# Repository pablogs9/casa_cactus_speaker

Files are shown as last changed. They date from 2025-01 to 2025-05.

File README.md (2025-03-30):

# Casa Cactus Speaker

3d
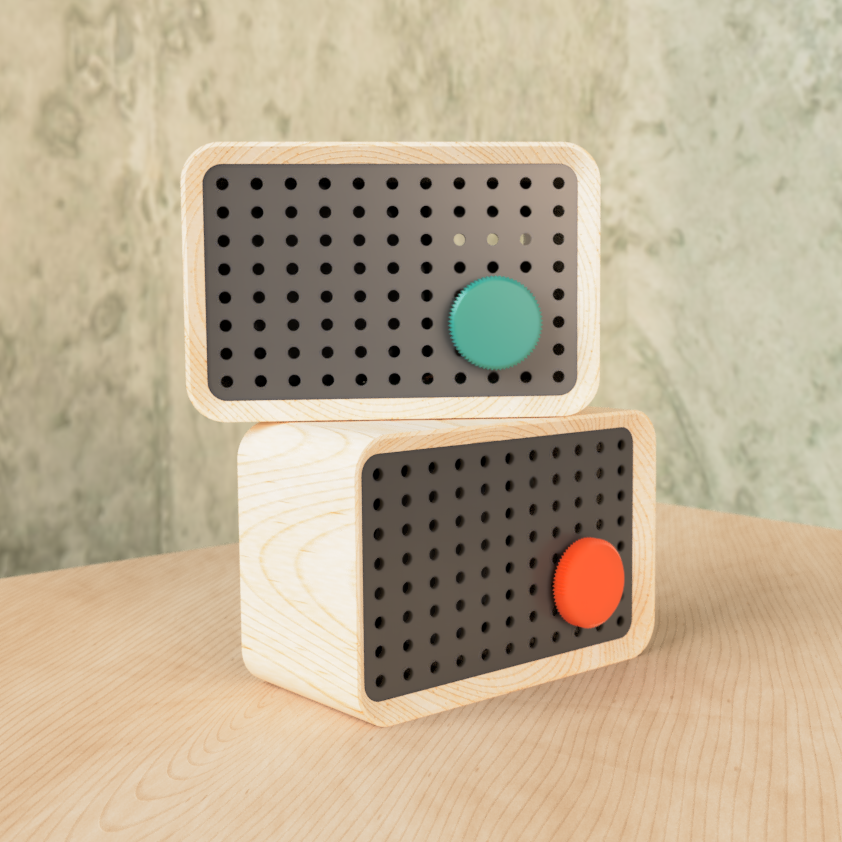
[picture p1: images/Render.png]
Render


Repository for a project featuring an ESP32-S3 and an I2S Class D amplifier for audio playback.

Created for a Makespace Madrid session to demonstrate a complete PCB design workflow, from schematic to JLCPCB fabrication.

**Companion slides: [here](https://docs.google.com/presentation/d/1glYFRo9XCKRI-qDjp1DA8M3mJohLk-lrxx0JoBPsboM/edit#slide=id.p)**

PCB
Schematic

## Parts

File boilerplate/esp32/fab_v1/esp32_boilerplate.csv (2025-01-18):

Designator | Value | LCSC part number
C1 | 0.1u | C14663
C2,C3 | 22u (Tantalum) | C129272
LED1,LED2 | KT-0603R | C2286
R1,R2 | 5k1 | C23186
R3,R7 | 100 | C22775
SW1,SW2 | TS-1187A-B-A-B | C318884
U1 | CH340C_C7464026 | C7464026
U2 | AMS1117-3.3 | C6186
U3 | ESP32-WROOM-32E(8MB) | C701342
USBC1 | TYPE-C-31-M-12 | C165948

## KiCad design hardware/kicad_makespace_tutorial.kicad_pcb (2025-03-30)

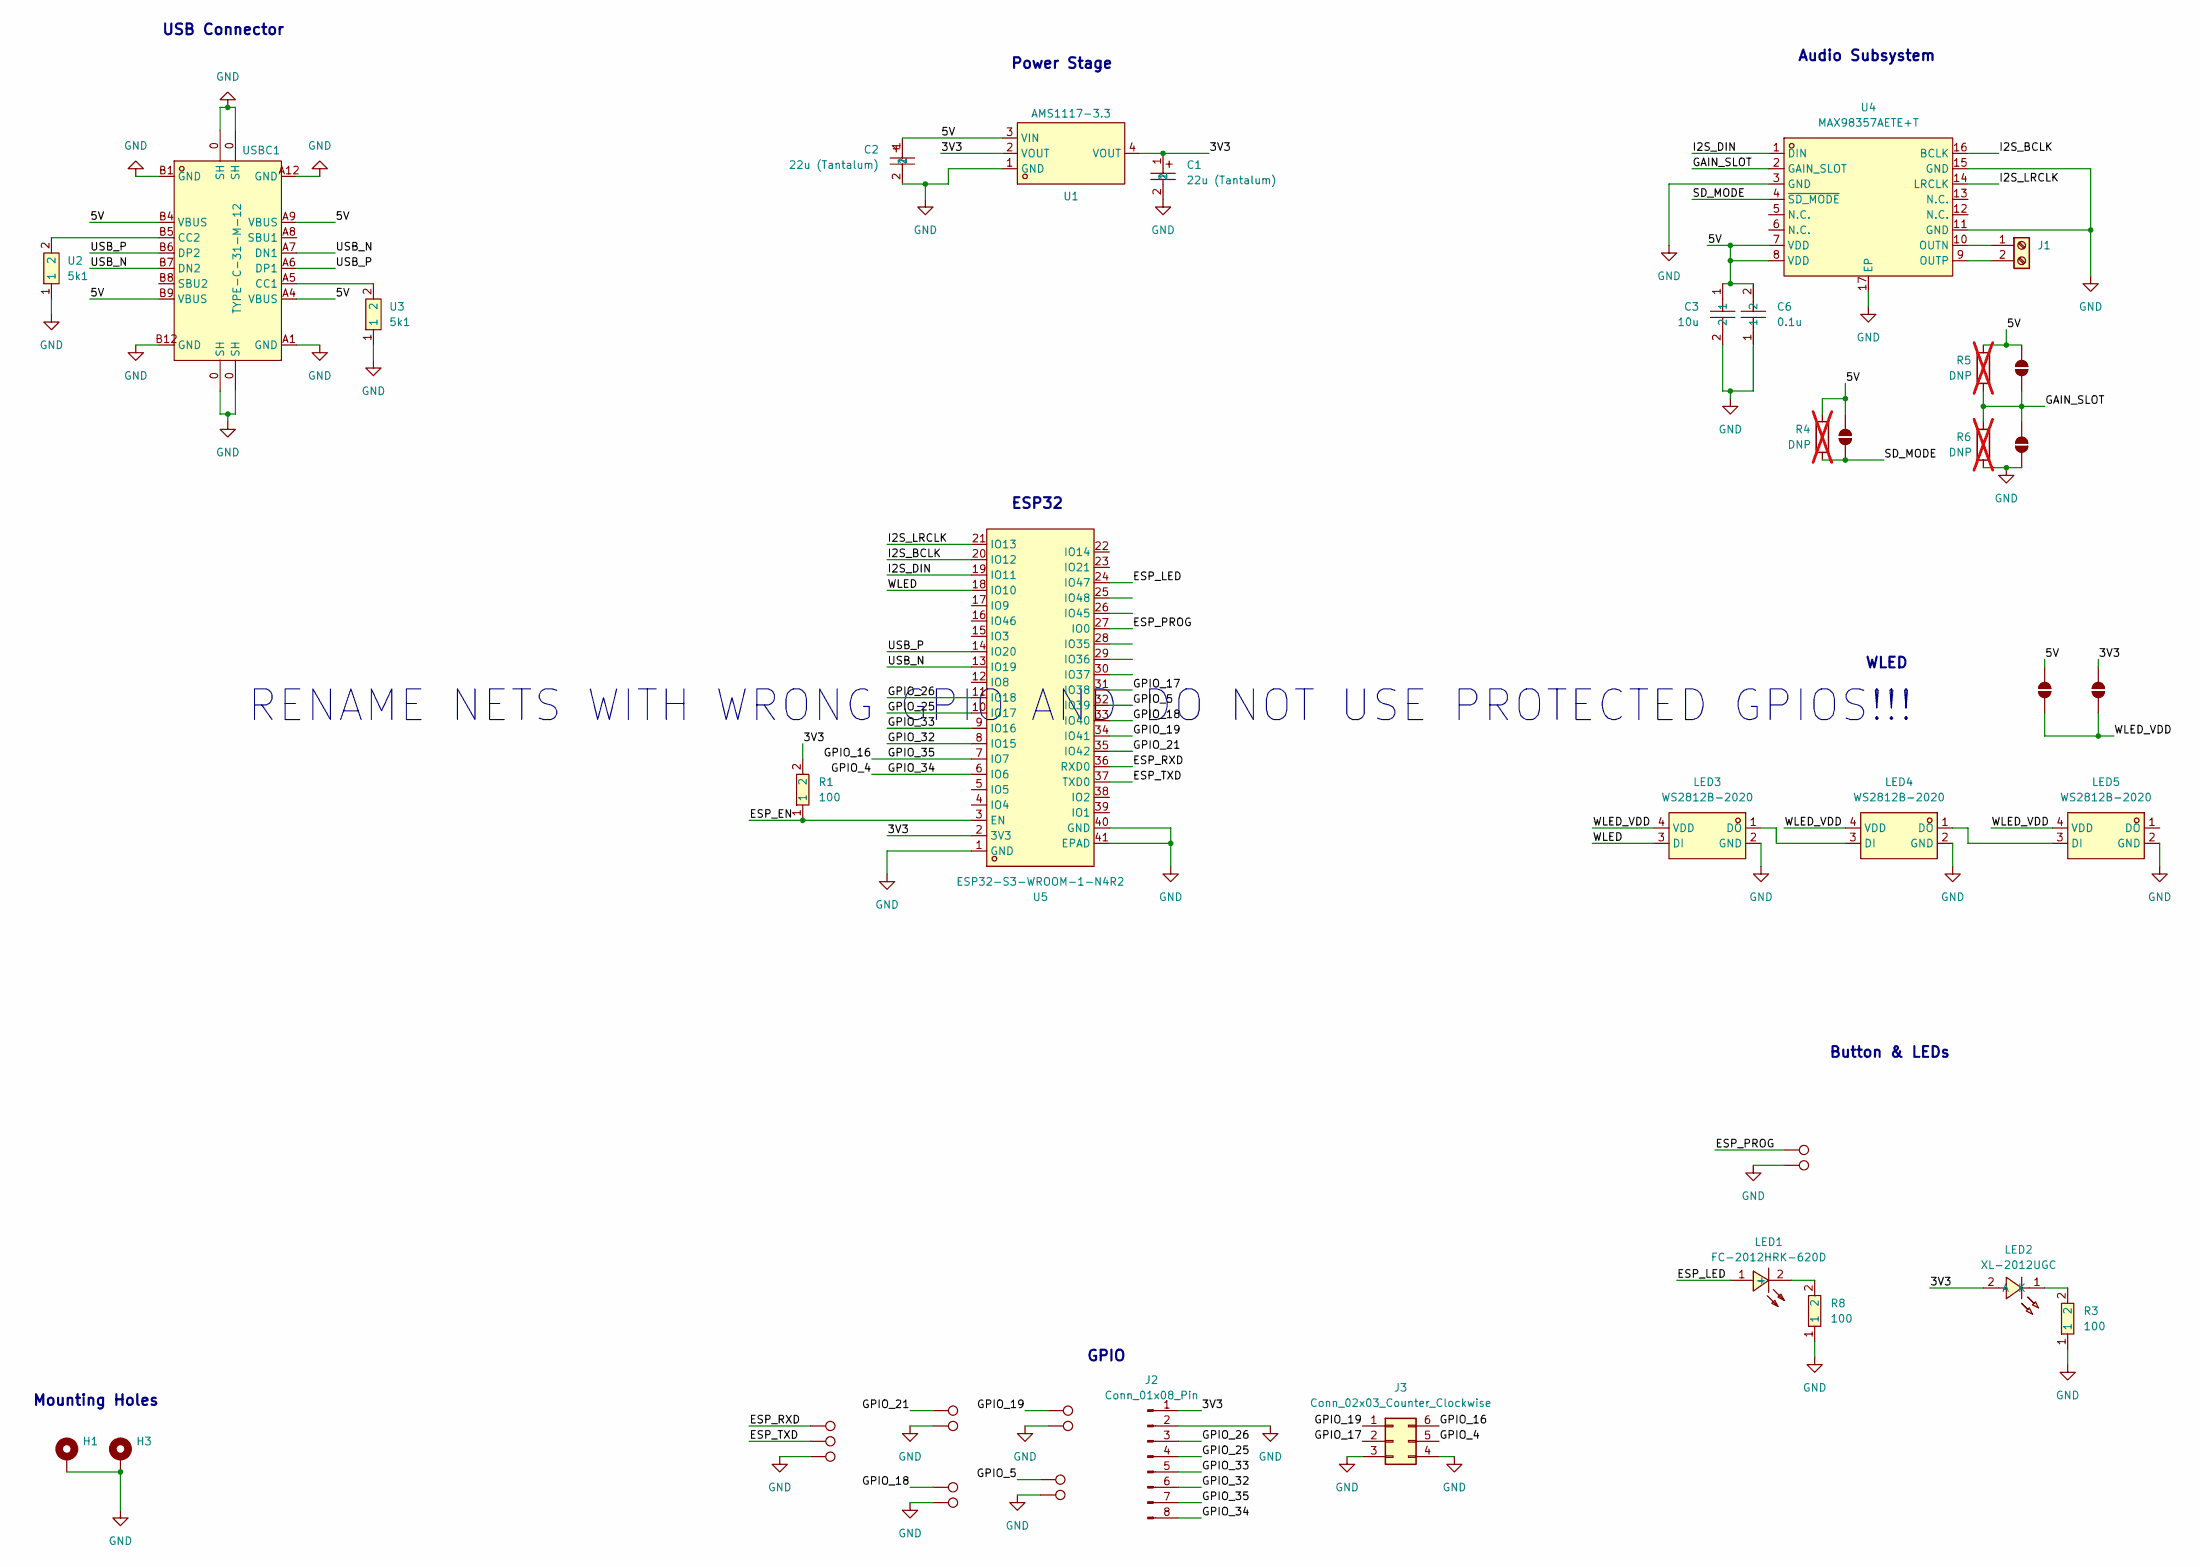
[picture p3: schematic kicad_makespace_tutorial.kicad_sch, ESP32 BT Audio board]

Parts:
C1, C2: 22u (Tantalum); CASE-A_3216; LCSC Part C129272
C3: 10u; C0805; LCSC Part C15850
C6: 0.1u; C0805; LCSC Part C49678
H1, H3: MountingHole_Pad_MP; MountingHole_2.7mm_M2.5_DIN965_Pad
J1: Screw_Terminal_01x02; CONN-TH_2P-P5.00_WJ128V-5.0-2P
J2: Conn_01x08_Pin; PinHeader_1x08_P1.27mm_Vertical_SMD_Pin1Right
J3: Conn_02x03_Counter_Clockwise; PinHeader_2x03_P2.54mm_Vertical
JP1, JP2, JP3, JP4, JP5: SolderJumper_2_Open; SolderJumper-2_P1.3mm_Open_TrianglePad1.0x1.5mm
LED1: FC-2012HRK-620D; LED0805-R-RD; LCSC Part C84256
LED2: XL-2012UGC; LED0805-RD_GREEN; LCSC Part C965815
LED3, LED4, LED5: WS2812B-2020; LED-SMD_4P-L2.0-W2.0-TL_WS2812B-2020; LCSC Part C965555
R1, R3, R8: 100; R0805; LCSC Part C17408
R4, R5, R6: DNP; R_0805_2012Metric_Pad1.20x1.40mm_HandSolder; not fitted
TP1, TP2, TP3, TP4, TP5, TP6, TP12, TP13, TP15, TP16, TP17, TP18, TP19: TestPoint; TestPoint_Pad_D1.0mm
U1: AMS1117-3.3; SOT-223-3_L6.5-W3.4-P2.30-LS7.0-BR; LCSC Part C6186
U2, U3: 5k1; R0805; LCSC Part C2930296
U4: MAX98357AETE+T; TQFN-16_L3.0-W3.0-P0.50-BL-EP1.5; LCSC Part C910544
U5: ESP32-S3-WROOM-1-N4R2; WIRELM-SMD_ESP32-S3-WROOM-1; LCSC Part C2913203
USBC1: TYPE-C-31-M-12; USB-C_SMD-TYPE-C-31-M-12; LCSC Part C165948

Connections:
/3V3: C1.1, J2.1, JP5.2 (B), LED2.2 (A), R1.2, U1.2 (VOUT), U1.4 (VOUT), U5.2 (3V3); also elsewhere on the board
/5V: C2.1, C3.1, C6.2, JP1.2 (B), JP3.2 (B), JP4.2 (B), R4.1, R5.1, U1.3 (VIN), U4.7 (VDD), U4.8 (VDD), USBC1.A4 (VBUS), USBC1.A9 (VBUS), USBC1.B4 (VBUS), USBC1.B9 (VBUS); also elsewhere on the board
/ESP_EN: R1.1, U5.3 (EN)
/ESP_LED: LED1.1 (+), U5.24 (IO47)
/ESP_PROG: TP18.1, U5.27 (IO0)
/ESP_RXD: TP15.1, U5.36 (RXD0)
/ESP_TXD: TP16.1, U5.37 (TXD0)
/GAIN_SLOT: JP2.2 (B), JP3.1 (A), R5.2, R6.1, U4.2 (GAIN_SLOT)
/GPIO_5: TP12.1, U5.32 (IO39)
/GPIO_16: J2.7, J3.6, U5.7 (IO7)
/GPIO_17: J3.2, U5.31 (IO38)
/GPIO_18: TP5.1, U5.33 (IO40)
/GPIO_19: J3.1, TP3.1, U5.34 (IO41)
/GPIO_21: TP2.1, U5.35 (IO42)
/GPIO_25: J2.4, U5.10 (IO17)
/GPIO_26: J2.3, U5.11 (IO18)
/GPIO_32: J2.6, U5.8 (IO15)
/GPIO_33: J2.5, U5.9 (IO16)
/GPIO_34: J2.8, J3.5, U5.6 (IO6)
/I2S_BCLK: U4.16 (BCLK), U5.20 (IO12)
/I2S_DIN: U4.1 (DIN), U5.19 (IO11)
/I2S_LRCLK: U4.14 (LRCLK), U5.21 (IO13)
/SD_MODE: JP1.1 (A), R4.2, U4.4 (~SD_MODE)
/USB_N: U5.13 (IO19), USBC1.A7 (DN1), USBC1.B7 (DN2)
/USB_P: U5.14 (IO20), USBC1.A6 (DP1), USBC1.B6 (DP2)
/WLED: LED3.3 (DI), U5.18 (IO10)
/WLED_VDD: JP4.1 (A), JP5.1 (A), LED3.4 (VDD), LED4.4 (VDD), LED5.4 (VDD); also elsewhere on the board
GND: C1.2, C2.2, C3.2, C6.1, H1.MP, H3.MP, J2.2, J3.3, J3.4, JP2.1 (A), LED3.2 (GND), LED4.2 (GND), LED5.2 (GND), R3.1, R6.2, R8.1, TP1.1, TP4.1, TP6.1, TP13.1, TP17.1, TP19.1, U1.1 (GND), U2.1, U3.1, U4.3 (GND), U4.11 (GND), U4.15 (GND), U4.17 (EP), U5.1 (GND), U5.40 (GND), U5.41 (EPAD), USBC1.0 (SH), USBC1.A1 (GND), USBC1.A12 (GND), USBC1.B1 (GND), USBC1.B12 (GND)
unnamed: J1.1, U4.10 (OUTN)
unnamed: J1.2, U4.9 (OUTP)
unnamed: LED1.2 (-), R8.2
unnamed: LED2.1 (K), R3.2
unnamed: LED3.1 (DO), LED4.3 (DI)
unnamed: LED4.1 (DO), LED5.3 (DI)
unnamed: U3.2, USBC1.A5 (CC1)
unnamed: U2.2, USBC1.B5 (CC2)

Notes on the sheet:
Button & LEDs
Mounting Holes
Power Stage
GPIO
Audio Subsystem
RENAME NETS WITH WRONG GPIO AND DO NOT USE PROTECTED GPIOS!!!
ESP32
WLED
USB Connector

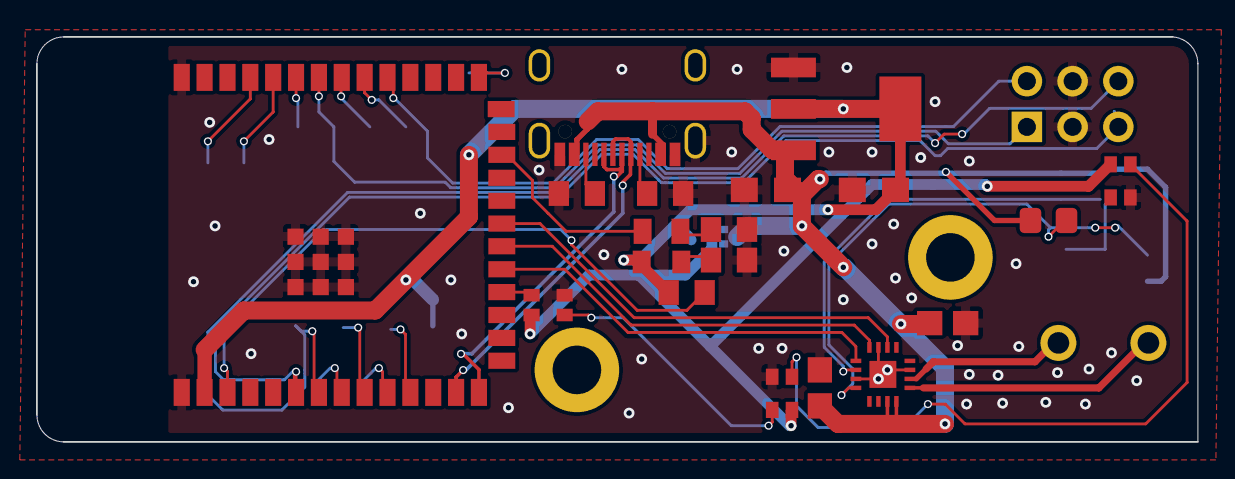
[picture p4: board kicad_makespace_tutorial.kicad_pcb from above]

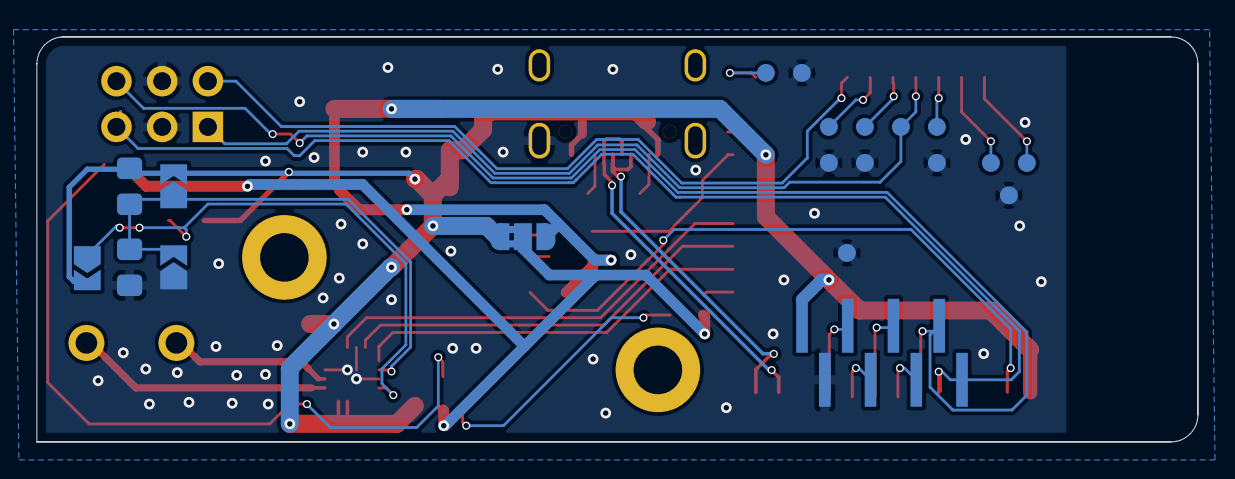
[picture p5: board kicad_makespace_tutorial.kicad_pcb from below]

Board: 2 copper layers, 64.5 x 22.5 mm, 43 parts (20 on the bottom side), 36 nets.

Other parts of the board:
JP6: Jumper_3_Bridged12; SolderJumper-3_P1.3mm_Bridged2Bar12_RoundedPad1.0x1.5mm_Num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

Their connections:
/3V3: JP6.3 (B); also elsewhere on the board
/5V: JP6.1 (A); also elsewhere on the board
/WLED_VDD: JP6.2 (C); also elsewhere on the board

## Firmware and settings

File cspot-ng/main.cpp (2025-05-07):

#include <iostream>

#include <interfaces/MDNSProvider.hpp>
#include <interfaces/HTTPServer.hpp>
#include <interfaces/Crypto.hpp>

#include <ZeroConf.hpp>
#include <Context.hpp>

#include <linux/LinuxCrytoMbedTLS.hpp>
#include <linux/LinuxTCPClient.hpp>
#include <linux/LinuxHTTPClient.hpp>
#include <linux/LinuxHTTPServer.hpp>
#include <linux/LinuxMDNSProvider.hpp>


using namespace cspot_ng;

int main()
{
    LinuxMDNSProvider mdns;
    LinuxTCPClient tcp_client;
    LinuxHTTPServer http_server;
    LinuxHTTPClient http_client;
    LinuxCrytoMbedTLS crypto;

    ZeroConf zeroconf(mdns, http_server, crypto);

    // Wait for authentication success
    while (!zeroconf.is_auth_success())
    {
        // Handle other tasks or sleep
        std::this_thread::sleep_for(std::chrono::milliseconds(1000));
        std::cout << "Waiting for authentication..." << std::endl;
    }

    Context context(zeroconf.get_blob(), http_client, tcp_client, crypto);

    if (!context.connect())
    {
        std::cerr << "Failed to connect to AP" << std::endl;
        return -1;
    }

    auto token = context.authenticate();

    if (token.empty())
    {
        std::cerr << "Authentication failed" << std::endl;
        return -1;
    }
    else
    {
        std::cout << "Authentication successful" << std::endl;
    }

    while (!zeroconf.is_closed())
    {
        context.spin();
    }

    return 0;
}

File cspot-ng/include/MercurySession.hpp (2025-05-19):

#pragma once

#include <ByteArray.hpp>
#include <ByteUtils.hpp>
#include <ShannonTCPClient.hpp>
#include <LoginBlob.hpp>

#include <protobuf/mercury.pb.h>
#include <protobuf/spirc.pb.h>

#include <cstring>
#include <ctime>

#include <iostream>

namespace cspot_ng
{
    struct MercurySession
    {
        MercurySession(const LoginBlob & blob, ShannonTCPClient & shannon_tcp_client)
            : blob_(blob)
            , shannon_tcp_client_(shannon_tcp_client)
        {
        }

        void spin(const uint8_t & command, const ByteArray & data)
        {
            if (!data.empty())
            {
                std::cout << "Received data: " << (uint32_t)command << " - " << data.size() << " bytes" << std::endl;

                switch (static_cast<RequestType>(command))
                {
                case RequestType::COUNTRY_CODE_RESPONSE:
                {
                    // printf("Received country code response: ");
                    // for (const auto& byte : data)
                    // {
                    //     printf("0x%02X ", byte);
                    // }
                    // printf("\n");

                    // const std::string country_code(data.begin(), data.end());
                    // std::cout << "Country code: " << country_code << std::endl;
                    break;
                }
                case RequestType::PING:
                {
                    // Ping sends server timepoint POSIX in seconds in the payload
                    uint32_t server_time = 0;
                    std::memcpy(&server_time, data.data(), sizeof(uint32_t));
                    // Convert to host byte order
                    server_time = ntohl(server_time);


                    // Calculate time offset
                    std::time_t now = std::time(nullptr);
                    time_offset_ = static_cast<int64_t>(now) - static_cast<int64_t>(server_time);

                    std::cout << "Received ping" << std::endl;
                    std::cout << "Server time: " << server_time << std::endl;
                    std::cout << "Time offset: " << time_offset_ << std::endl;

                    // Send a PONG_ACK response
                    ShannonTCPClient::ShannonPacket pong_packet;
                    pong_packet.command = static_cast<uint8_t>(RequestType::PING_RESPONSE);
                    pong_packet.data = data; // Echo the data back
                    shannon_tcp_client_.send(pong_packet);

                    if(mercury_state_ == MercuryState::WAITING_FIRST_PING)
                    {
                        subscribe_to_mercury();
                        mercury_state_ = MercuryState::SUBSCRIBING_TO_MERCURY_WAITING;
                    }

                    break;
                }
                case RequestType::SEND:
                case RequestType::SUB:
                case RequestType::UNSUB:
                {
                    // std::cout << "Received Mercury SEND/SUB/UNSUB packet" << std::endl;
                    // print_byte_array(data);

                    if(mercury_state_ == MercuryState::SUBSCRIBING_TO_MERCURY_WAITING)
                    {
                        decode_mercury_response(data, true);
                    }
                    else
                    {
                        std::cout << "Received data: " << (uint32_t)command << " - " << data.size() << " bytes" << std::endl;
                    }
                    break;
                    }
                case RequestType::SUBRES: {
                    std::cout << "----------- Received SUBRES packet" << std::endl;
                    std::cout << "Received data: " << (uint32_t)command << " - " << data.size() << " bytes" << std::endl;

                    decode_mercury_response(data, false);
                    break;
                }
                default:
                    break;
                }
            }
        }

    private:

        enum class RequestType : uint8_t {
            SUB = 0xB3,
            UNSUB = 0xB4,
            SUBRES = 0xB5,
            SEND = 0xB2,
            GET = 0xFF,  // Shitty workaround, it's value is actually same as SEND
            PING = 0x04,
            PING_RESPONSE = 0x49,
            PONG_ACK = 0x4A,
            AUDIO_CHUNK_REQUEST_COMMAND = 0x08,
            AUDIO_CHUNK_SUCCESS_RESPONSE = 0x09,
            AUDIO_CHUNK_FAILURE_RESPONSE = 0x0A,
            AUDIO_KEY_REQUEST_COMMAND = 0x0C,
            AUDIO_KEY_SUCCESS_RESPONSE = 0x0D,
            AUDIO_KEY_FAILURE_RESPONSE = 0x0E,
            COUNTRY_CODE_RESPONSE = 0x1B,
          };

        enum class MercuryState
        {
            WAITING_FIRST_PING = 0,
            SUBSCRIBING_TO_MERCURY,
            SUBSCRIBING_TO_MERCURY_WAITING,
            SENDING_HELLO,
            SENDING_HELLO_WAITING
        };

        const LoginBlob & blob_;
        ShannonTCPClient & shannon_tcp_client_;

        MercuryState mercury_state_ = MercuryState::WAITING_FIRST_PING;
        uint64_t sequence_id_ = 1;
        uint32_t spirc_sequence_id_ = 0;
        int64_t time_offset_ = 0;

        void subscribe_to_mercury()
        {
            // Create the message
            ByteArray message = {};

            // Serialize sequence ID size
            uint16_t sequence_id_size = sizeof(sequence_id_);
            sequence_id_size = htons(sequence_id_size);
            append_to_byte_array(message, sequence_id_size);

            // Serialize sequence ID
            append_to_byte_array(message, hton64(sequence_id_));
            sequence_id_++;

            // Serialize a 0x01 byte
            uint8_t zero_byte = 0x01;
            append_to_byte_array(message, zero_byte);

            // Serialize the number of payloads (only the header in this case)
            uint16_t payload_count = 1;
            payload_count = htons(payload_count);
            append_to_byte_array(message, payload_count);

            // CREATE THE PAYLOAD
            Header mercury_header = {};

            const std::string uri = "hm://remote/user/" + blob_.username() + "/";
            mercury_header.has_uri = true;
            protobuffer_set_string(uri, mercury_header.uri);

            const std::string method = "SUB";
            mercury_header.has_method = true;
            protobuffer_set_string(method, mercury_header.method);

            auto encoded_header = ProtoBuffer<Header>::encode(mercury_header, Header_fields);

            // Serialize the payload size
            uint16_t payload_size = encoded_header.size();
            payload_size = htons(payload_size);
            append_to_byte_array(message, payload_size);

            // Append the payload
            append_to_byte_array(message, encoded_header);

            // Print the message for debugging
            std::cout << "Sending subscribe message: " << std::endl;
            print_byte_array(message);
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

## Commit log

2025-01-18 Routed ESP32 boilerplate
    [esp32_boilerplate-CmtUser.gbr, esp32_boilerplate-CuBottom.gbl, esp32_boilerplate-CuTop.gtl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]
2025-01-29 Bump Desing
    [bom.csv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]
2025-02-19 Final design
    [kicad_makespace_tutorial.kicad_pcb, kicad_makespace_tutorial.kicad_sch]
2025-03-30 Final Updates
    [kicad_makespace_tutorial-CmtUser.gbr, kicad_makespace_tutorial-CuBottom.gbl, kicad_makespace_tutorial-CuTop.gtl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]
2025-03-30 Remove boilerplate
    [esp32_boilerplate.kicad_pcb, esp32_boilerplate.kicad_sch, rp2040_boilerplate.kicad_pcb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]
2025-03-30 Rework folders
    [kicad_makespace_tutorial-CmtUser.gbr, kicad_makespace_tutorial-CuBottom.gbl, kicad_makespace_tutorial-CuTop.gtl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]
2025-03-30 Add firmware
    [partitions.csv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]
2025-04-01 Initial efforts
    [partitions.csv]
2025-04-02 Working stage
2025-04-02 Ignore original folders
    [partitions.csv]
